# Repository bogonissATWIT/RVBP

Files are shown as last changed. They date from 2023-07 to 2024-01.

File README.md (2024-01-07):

# RVBP - Recycled Vape Battery Pack
## Sam Bogonis - Wentworth Institute of Technology 2023
#### Basic Description:
Hardware platform to harvest 13450 lithium-ion cells from disposable vape batteries and recycle them into a smart IoT WiFi-enabled USB battery pack with a web-controlled dashboard UI.
pic of final product working powered by pack
#### Platform Overview:
- 2 x USB-A Outputs
- ESP32_DEVKITC_32D Microcontroller
- 21V@1A DC Wall Charger w/ indicator LED
- 555 Power LED circuit
- DHT22 - Temperature/Humidity Sensor
- I2C 0.96" OLED Display
- Screw terminal connections for up to three packs of 5 lithium-ion cells in series
- Scalable for additional capacity
- Exposed GPIO headers for additional functionality
final-assembled-4

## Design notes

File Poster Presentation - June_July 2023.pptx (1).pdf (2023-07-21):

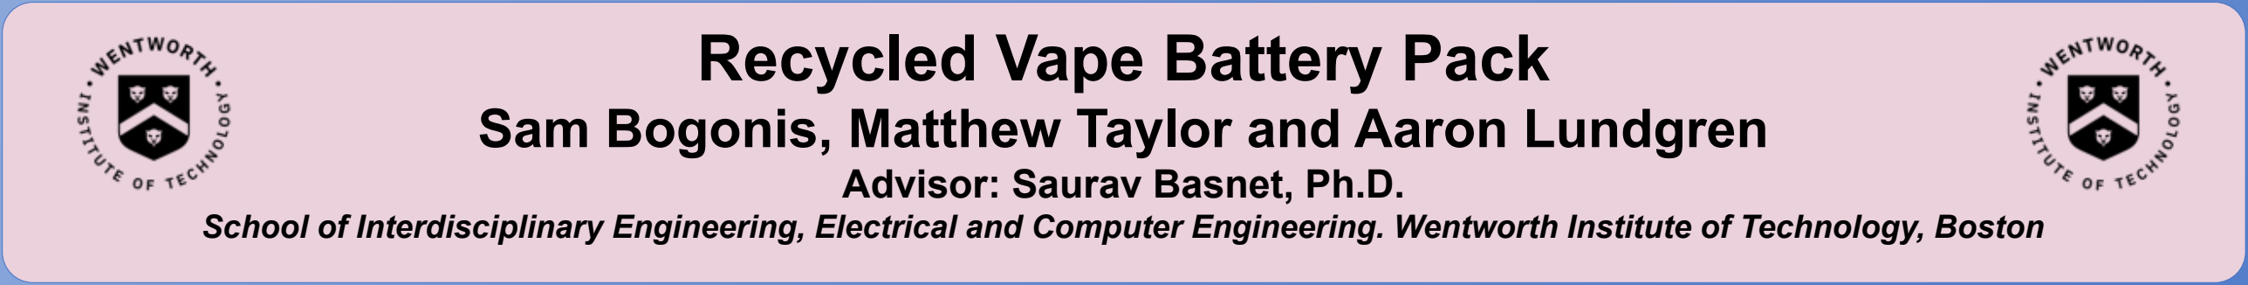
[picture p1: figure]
Recycled Vape Battery Pack; Advisor: Saurav Basnet, Ph.D.

# Sam Bogonis, Matthew Taylor and Aaron Lundgren

School of Interdisciplinary Engineering, Electrical and Computer Engineering. Wentworth Institute of Technology, Boston

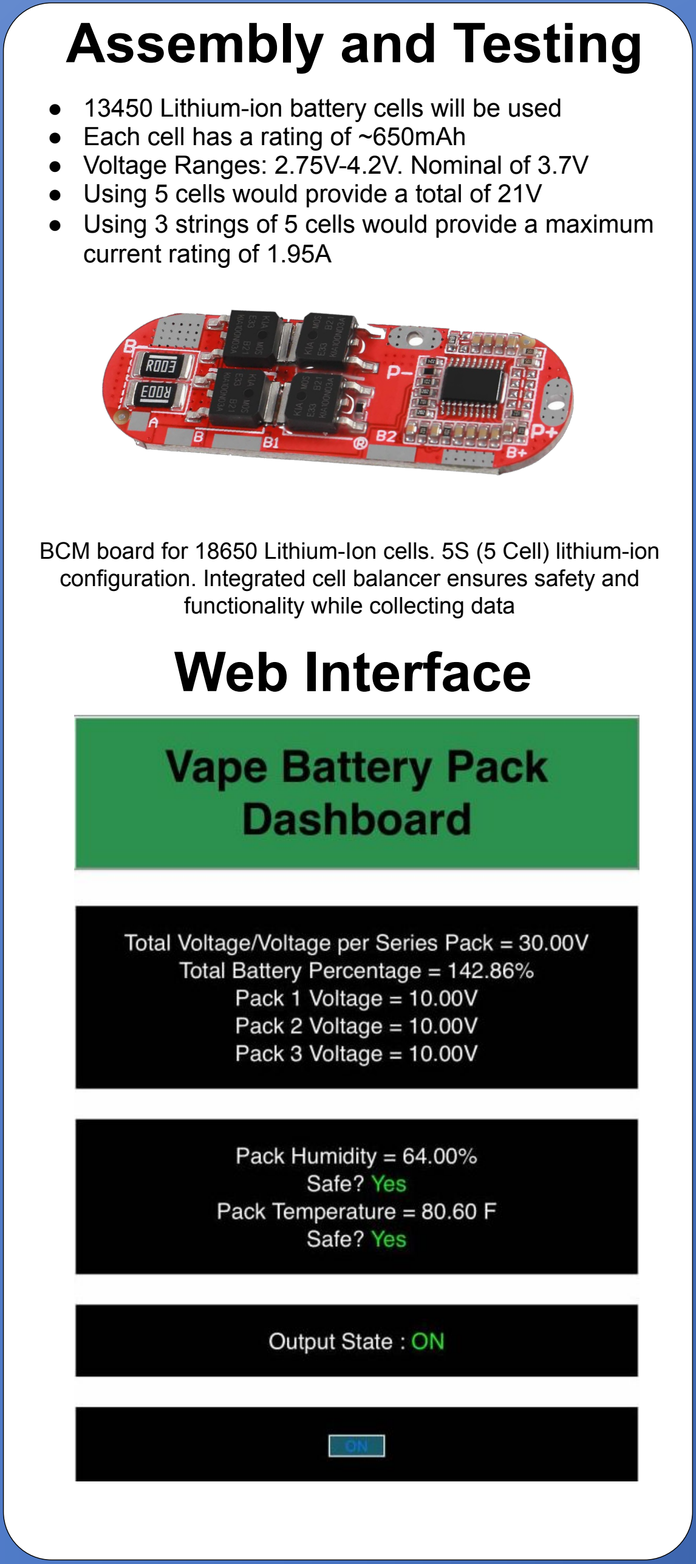
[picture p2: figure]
● Each cell has a rating of ~650mAh; current rating of 1.95A; functionality while collecting data Web Interface
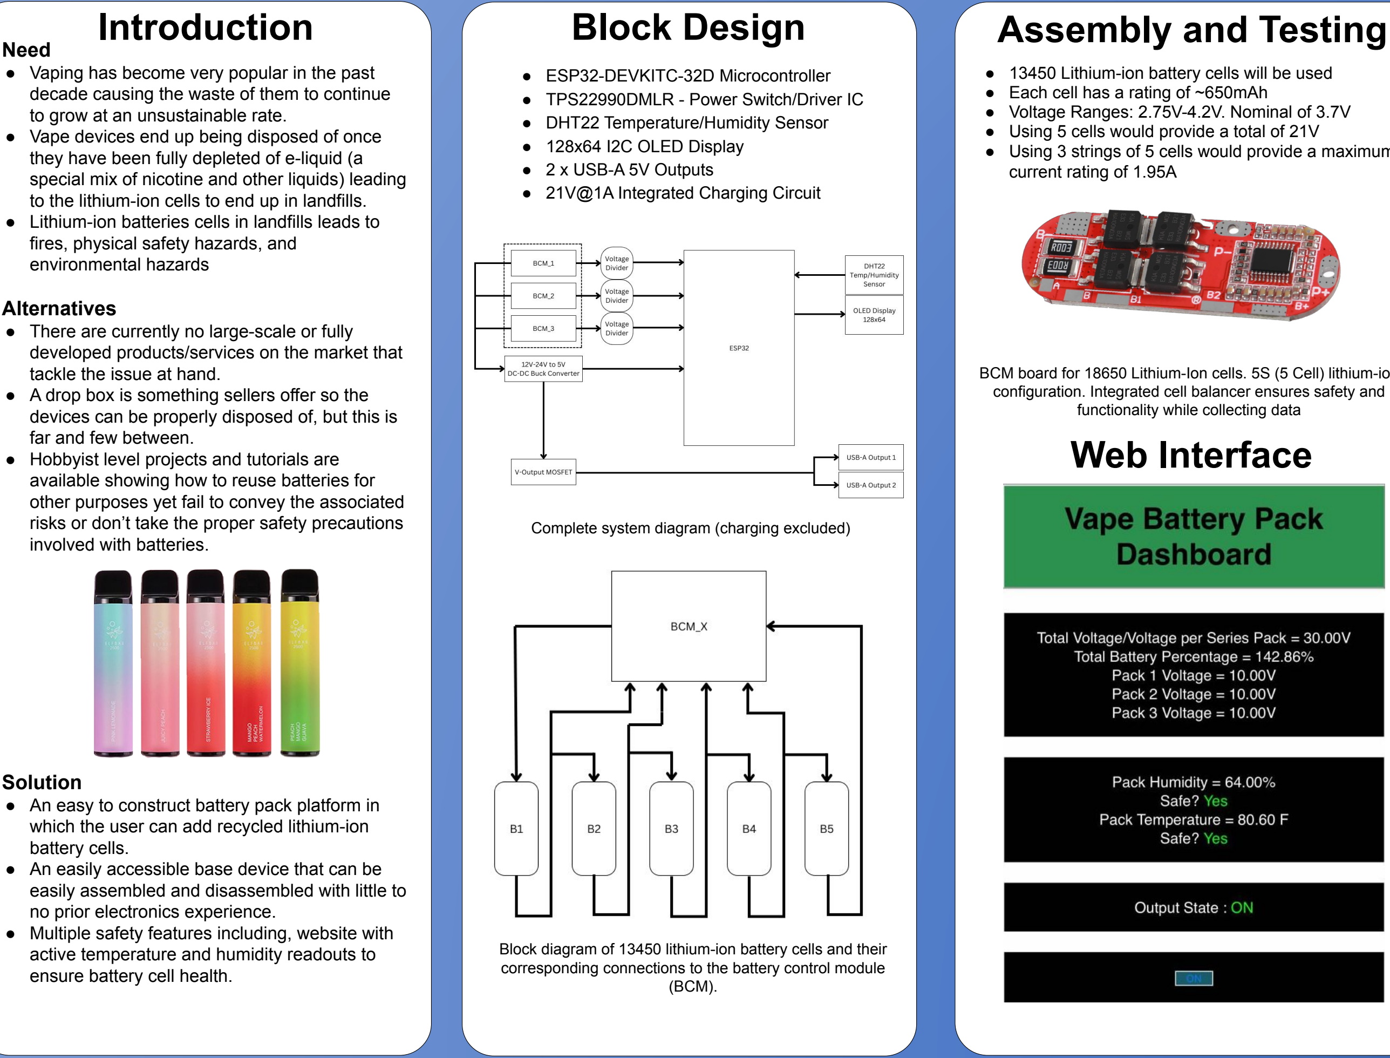
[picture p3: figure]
Block Design; ● ESP32-DEVKITC-32D Microcontroller ● TPS22990DMLR - Power Switch/Driver IC ● DHT22 Temperature/Humidity Sensor ● 128x64 I2C OLED Display ● 2 x USB-A 5V Outputs ● 21V@1A Integrated Charging Circuit; Need; to grow at an unsustainable rate.; fires, physical safety hazards, and environmental hazards; Alternatives; tackle the issue at hand.; far and few between.; involved with batteries.; Solution; battery cells.; no prior electronics experience.; ensure battery cell health.; Introduction; Assembly and Testing; Complete system diagram (charging excluded); (BCM).

- 13450 Lithium-ion battery cells will be used
- Voltage Ranges: 2.75V-4.2V. Nominal of 3.7V
- Using 5 cells would provide a total of 21V
- Using 3 strings of 5 cells would provide a maximum

# Results

[1] A. Semmens, “An innovative scheme to put 'disposable' e-cig batteries to new use,” ECigIntelligence, 15-Jul-2022. [Online]. Available: https://ecigintelligence.com/an-innovative-and-unexpected-scheme-to-put-disposable-e-cig-batteries-to-new-use/. [Accessed: 20-Mar-2023].
[2] D. Moore, “Two vapes thrown away every second,” Circular Online, 15-Jul-2022. [Online]. Available: https://www.circularonline.co.uk/news/two-vapes-thrown-away-every-second/. [Accessed: 20-Mar-2023].
[3] J. Heelan, E. Gratz, Z. Zheng, Q. Wang, M. Chen, D. Apelian, and Y. Wang, “Current and prospective Li-ion battery recycling and Recovery Processes - Jom,” SpringerLink, 20-Jun-2016. [Online]. Available: https://link.springer.com/article/10.1007/s11837-016-1994-y. [Accessed: 20-Mar-2023].
[4] Opengreenenergy and Instructables, “DIY Professional 18650 Battery Pack,” Instructables, 29-Jul-2022. [Online]. Available: https://www.instructables.com/DIY-Professional-18650-Battery-Pack/. [Accessed: 20-Mar-2023].

Conclusions
The product that this project covers is only a start to solving the issue of waste produced from disposable vapes. With the popularity continuing to grow of these devices it is important that action is taken that allows for reuse of the precious lithium inside. This product aims to be a consumer solution, giving access to a battery pack that will be easy to assemble with simple instructions.

Future Directions
An expansion of this product would take this to a manufacturer/merchant level. Drop-boxes would offer incentives as collection for the batteries. Battery cells would be harvested and used to mass produce the product or used in regular devices if battery health is optimal. Improving to that size would greatly impact the situation of vape waste.

References

- Vaping has become very popular in the past decade causing the waste of them to continue
- Vape devices end up being disposed of once they have been fully depleted of e-liquid (a special mix of nicotine and other liquids) leading to the lithium-ion cells to end up in landfills.
- Lithium-ion batteries cells in landfills leads to
- There are currently no large-scale or fully developed products/services on the market that
- A drop box is something sellers offer so the devices can be properly disposed of, but this is
- Hobbyist level projects and tutorials are available showing how to reuse batteries for other purposes yet fail to convey the associated risks or don’t take the proper safety precautions
- An easy to construct battery pack platform in which the user can add recycled lithium-ion
- An easily accessible base device that can be easily assembled and disassembled with little to
- Multiple safety features including, website with active temperature and humidity readouts to

Block diagram of 13450 lithium-ion battery cells and their corresponding connections to the battery control module

BCM board for 18650 Lithium-Ion cells. 5S (5 Cell) lithium-ion configuration. Integrated cell balancer ensures safety and

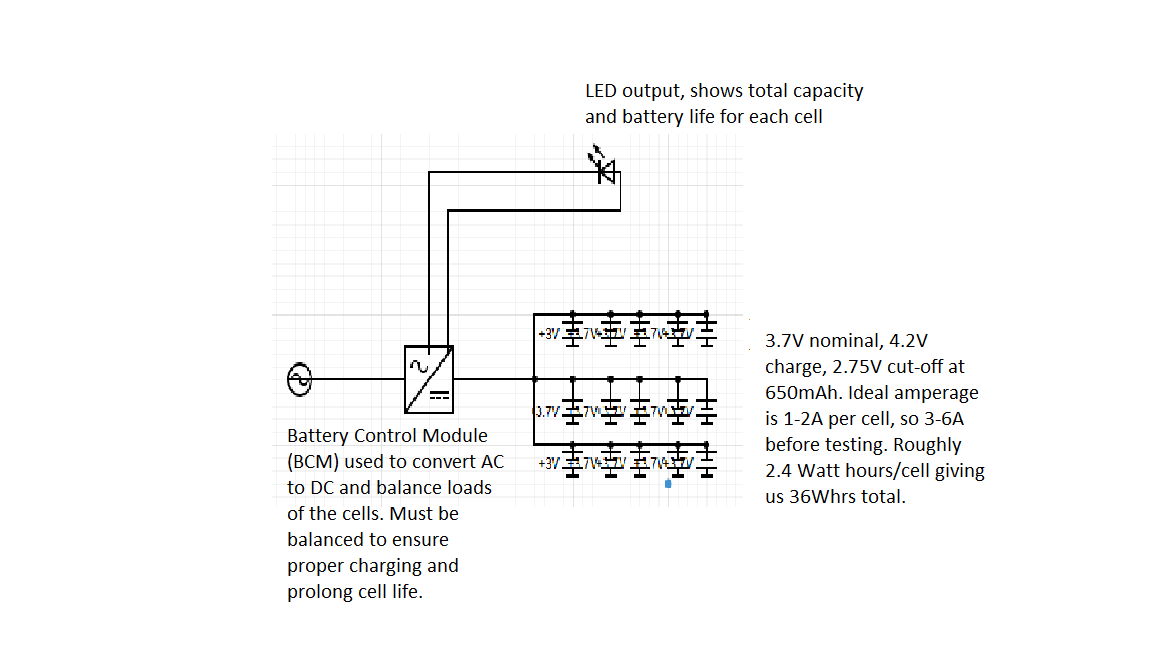
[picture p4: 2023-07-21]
System Block Diagram/circuit prototype.png

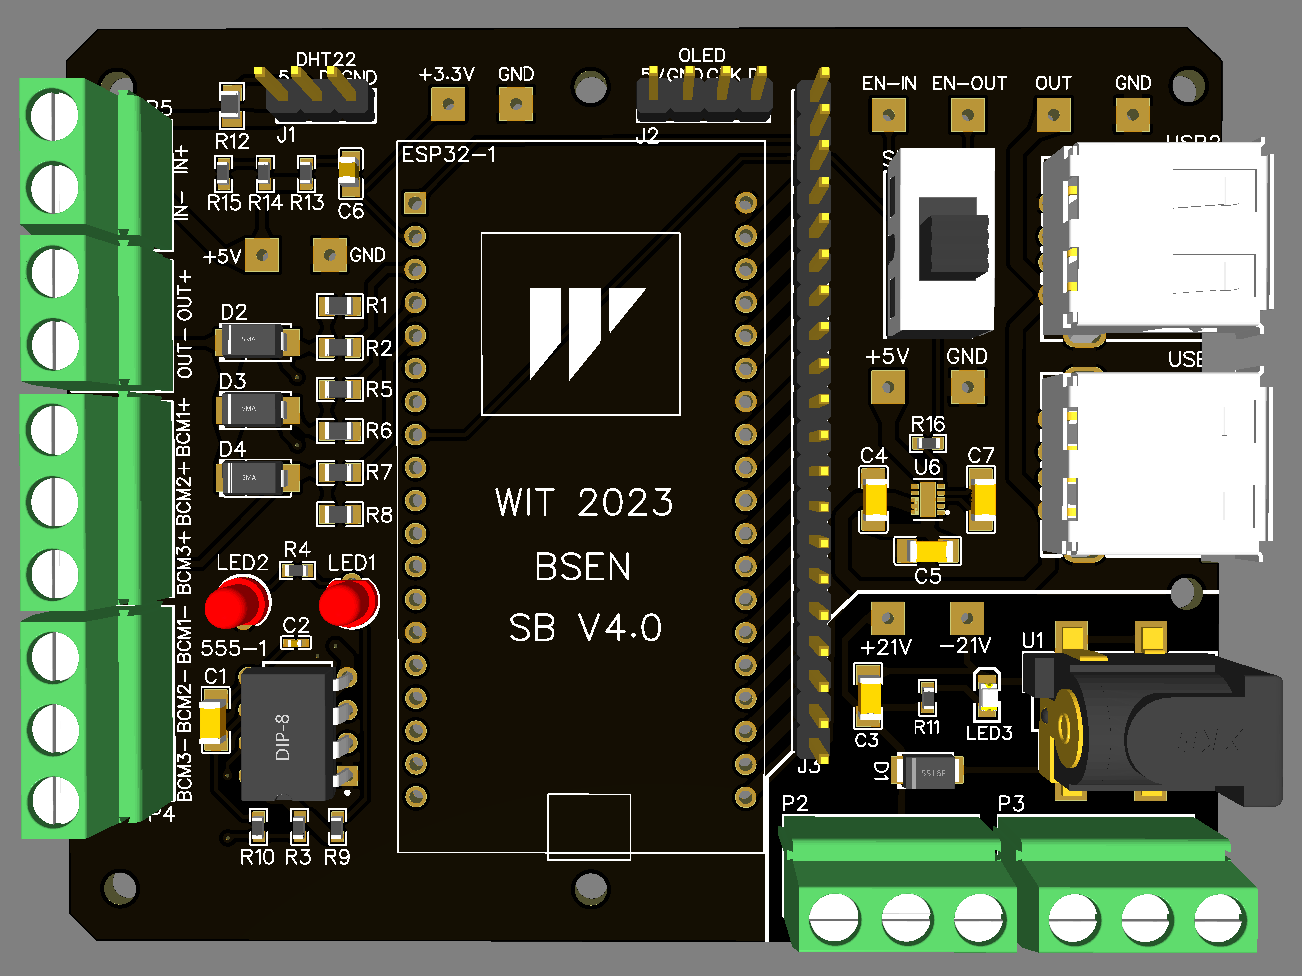
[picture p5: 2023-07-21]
V4.0/V4-Model1.png

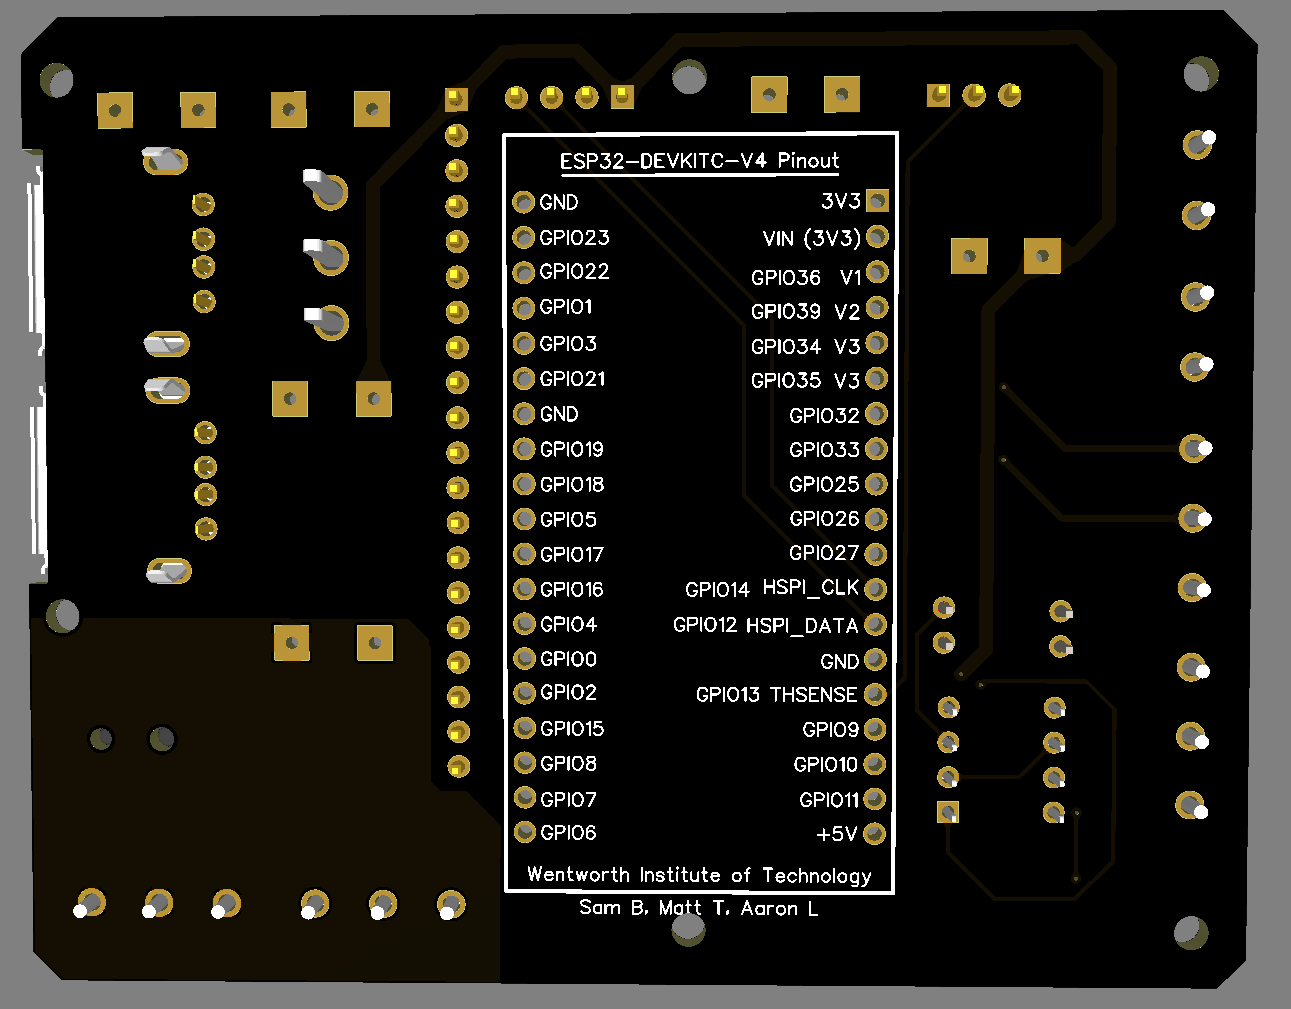
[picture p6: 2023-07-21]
V4.0/V4-Model2.png

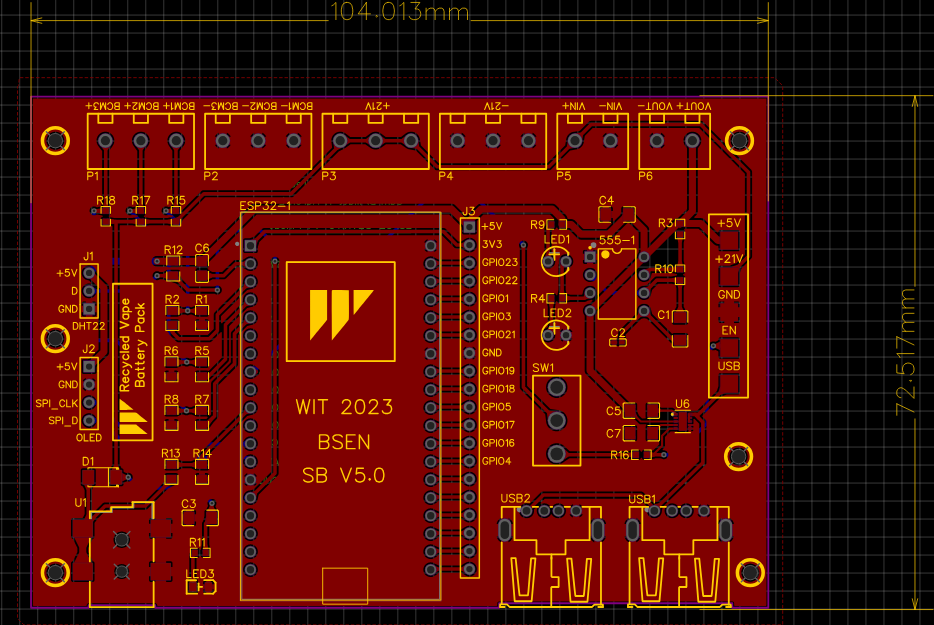
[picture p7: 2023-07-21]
V5.0 - Final/PCB-1.png

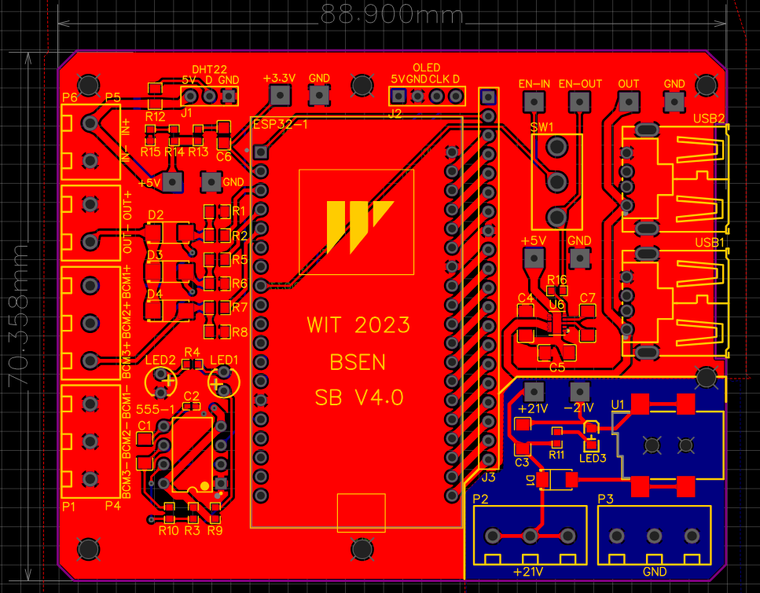
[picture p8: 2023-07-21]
V4.0/V4-Final.png

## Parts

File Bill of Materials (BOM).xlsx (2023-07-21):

QTY | Name | Price | Price (Calculated) | Complete | URL
1 | 21V/1A Wall Charger | $8.17 | $8.17 |  | https://www.amazon.com/dp/B09THJCD8Q/?coliid=I156PEE71VQ26Z&colid=3LVNL31IXG1PE | Delivered
1 | DHT22 Temp/Humidity Sensor | $13.99 | $13.99 |  | https://www.amazon.com/dp/B0795F19W6/?coliid=IOJO4XWYG3GXL&colid=3LVNL31IXG1PE | Waiting
1 | 128x63 0.96inch OLED Display | $10.99 | $10.99 |  | https://www.amazon.com/dp/B0BK4QVR1F/?coliid=I14K05QKVUBQC6&colid=3LVNL31IXG1PE | On the way
1 | Adhesive Foam Pad 1/4"x4"x4" | $10.88 | $10.88 |  | https://www.amazon.com/dp/B06ZY83SZJ/?coliid=IFWQ253B9FA2G&colid=3LVNL31IXG1PE | Not yet acquired
2 | 2pcs 21V 5S BMS PCB | $9.99 | $19.98 |  | https://www.amazon.com/dp/B08R9G6S7Y/?coliid=I1HXKP7RCFCFKY&colid=3LVNL31IXG1PE
2 | 25W DC-DC 12V/24V-5V Buck Reg. | $12.99 | $25.98 |  | https://www.amazon.com/dp/B09SD9SH8C/?coliid=I266TNYB8VDANJ&colid=3LVNL31IXG1PE
1 | 2" Nickel Strips, 50pcs | $5.49 | $5.49 |  | https://www.amazon.com/dp/B07PQP55CM?psc=1&ref=ppx_yo2ov_dt_b_product_details
10 | TPS22990DMLR | $0.93 | $9.30 |  | https://www.digikey.com/en/products/detail/texas-instruments/TPS22990DMLR/6148959
6 | ESP32-DEVKITC-32D Microcontroller | $10.00 | $60.00 |  | https://www.digikey.com/en/products/detail/espressif-systems/ESP32-DEVKITC-32D/9356990
1 | Prototype PCB (5)Manufacture/(2)Assembly | $57.29 | $57.29
1 | Final PCB (10)Manufacture/(6)Assembly | $94.13 | $94.13
3 | 3pcs 21V Balancer PCB | $7.99 | $23.97 |  | https://www.amazon.com/dp/B09F9K7X34?psc=1&ref=ppx_yo2ov_dt_b_product_details
1 | 20pairs Nickel Plate Spring Contacts | $8.99 | $8.99 |  | https://www.amazon.com/dp/B07HRTMY5T?psc=1&ref=ppx_yo2ov_dt_b_product_details
 |  | Total: | $349.16
 |  | Remaining: | $193.42
 |  | Split Cost (3): | $64.47

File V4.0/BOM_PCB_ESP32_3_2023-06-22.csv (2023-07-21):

ID | Name | Designator | Footprint | Quantity | Manufacturer Part | Manufacturer | Supplier | Supplier Part | Price
1 | DC-005-2.5A-2.5-SMT | U1 | DC-IN-TH_XKB_DC-005-2.5A-2.5-SMT | 1 | DC-005-2.5A-2.5-SMT | XKB Connectivity(中国星坤) | LCSC | C2880544 | 0.324
2 | WJ126V-5.0-2P | P5,P6 | CONN-TH_WJ126V-5.0-2P | 2 | WJ126V-5.0-2P | KANGNEX(康奈克斯电气) | LCSC | C8404 | 0.068
3 | FC-2012HRK-620D | LED3 | LED0805-RD_RED | 1 | NCD0805R1 | 国星光电 | LCSC | C84256 | 0.011
4 | 1kΩ | R11,R3,R4,R9 | R0603 | 4 | 0603WAF1001T5E | UNI-ROYAL(厚声) | LCSC | C21190 | 0.001
5 | NE555P | 555-1 | DIP-8_L9.8-W6.6-P2.54-LS7.6-BL | 1 | NE555P | TI(德州仪器) | LCSC | C46749 | 0.262
6 | 10uF | C1,C5,C7 | C1206 | 3 | CS3216X7R106K250NRI | SAMWHA(三和) | LCSC | C513767 | 0.039
7 | 22uF | C3,C4 | C1206 | 2 | CS3216X5R226K160NRI | SAMWHA(三和) | LCSC | C513771 | 0.064
8 | 10nF | C2 | C0402 | 1 | GRM155B11E103KA01D | muRata(村田) | LCSC | C85947 | 0.002
9 | 200nF | C6 | C0805 | 1 | NL0805B204K500CPBN | HUI JU(汇聚) | LCSC | C918135 | 0.012
10 | PMEG3020EP,115 | D1 | SMAF_L3.8-W2.5-LS4.7-RD | 1 | PMEG3020EP,115 | Nexperia(安世) | LCSC | C513108 | 0.218
11 | SS34_C8678 | D2,D3,D4 | SMA_L4.3-W2.6-LS5.2-RD | 3 | SS34 | MDD | LCSC | C8678 | 0.024
12 | ESP32-DEVKITC-32D_ESP32-DEVKITC-32D | ESP32-1 | ESP32-DEVKITC-32D_MODULE_ESP32-DEVKITC-32D | 1
13 | HDR-M-2.54_1x3 | J1 | HDR-M-2.54_1X3 | 1 |  |  | LCSC | C180248 | 0.197
14 | HDR-M-2.54_1x4 | J2 | HDR-M-2.54_1X4 | 1 |  |  | LCSC | C124378 | 0.042
15 | HDR-M-2.54_1x20 | J3 | HDR-M-2.54_1X20 | 1 |  |  | LCSC | C50981 | 0.091
16 | *1 | LED1,LED2 | LED-TH_BD3.8-P2.54-FD | 2 | 204-10SYGD/S530-E3 | EVERLIGHT(亿光) | LCSC | C85161 | 0.029
17 | WJ126V-5.0-3P | P1,P2,P3,P4 | CONN-TH_3P-P5.00_WJ126V-5.0-3P | 4 | WJ126V-5.0-3P | KANGNEX(康奈克斯电气) | LCSC | C8401 | 0.101
18 | 3kΩ | R1,R6,R8 | R0805 | 3 | 0805W8F3001T5E | UNI-ROYAL(厚声) | LCSC | C17661 | 0.002
19 | 20kΩ | R2,R5,R7 | R0805 | 3 | 0805W8F2002T5E | UNI-ROYAL(厚声) | LCSC | C4328 | 0.002
20 | 10kΩ | R12 | R0805 | 1 | 0805W8F1002T5E | UNI-ROYAL(厚声) | LCSC | C17414 | 0.001
21 | 100kΩ | R10,R13,R14,R15 | R0603 | 4 | 0603WAF1003T5E | UNI-ROYAL(厚声) | LCSC | C25803 | 0.001
22 | 0Ω | R16 | R0603 | 1 | 0603WAF0000T5E | UNI-ROYAL(厚声) | LCSC | C21189 | 0.001
23 | SS-12D10L5 | SW1 | SW-TH_SS-12D10L5 | 1 | SS-12D10L5 | XKB Connectivity(中国星坤) | LCSC | C319012 | 0.283
24 | TPS22990DMLR | U6 | WSON-10_L3.0-W2.0-P0.50-BL-EP_TI_DML | 1 | TPS22990DMLR | TI(德州仪器) | LCSC | C962990 | 0.741
25 | U-USBAR04P-F001 | USB1,USB2 | USB-A-TH_USB-302-T | 2 | U-USBAR04P-F002 | Ckmtw(灿科盟) | LCSC | C386736 | 0.174

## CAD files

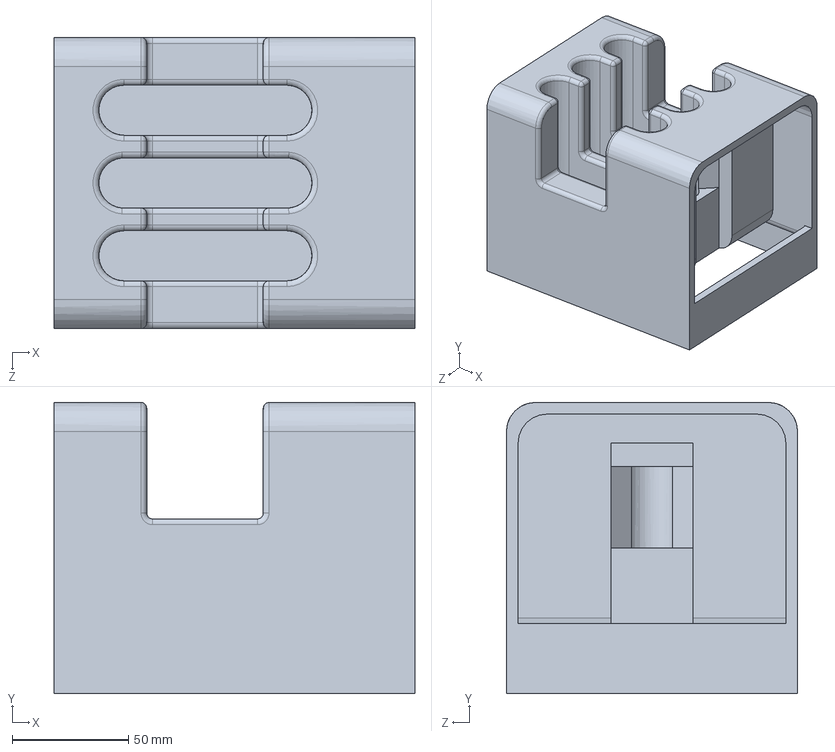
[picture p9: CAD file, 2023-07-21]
Solidworks/Enclosure.SLDPRT
155.0 x 125.0 x 125.0 mm

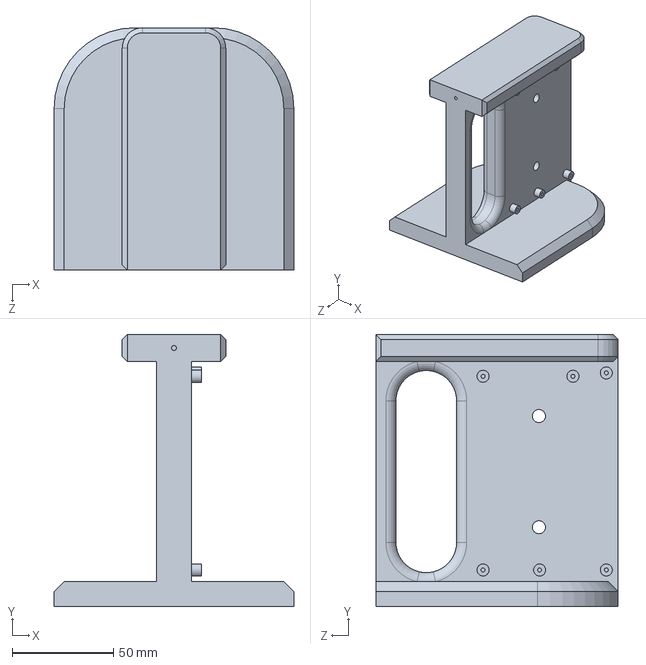
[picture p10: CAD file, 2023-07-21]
Solidworks/presentation base.SLDPRT
118.7 x 134.6 x 120.0 mm

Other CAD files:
Solidworks/Enclosure.STL
Solidworks/presentation base.STL

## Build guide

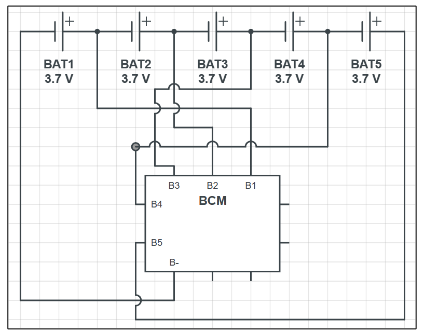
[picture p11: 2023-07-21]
System Block Diagram/Cell setup.png

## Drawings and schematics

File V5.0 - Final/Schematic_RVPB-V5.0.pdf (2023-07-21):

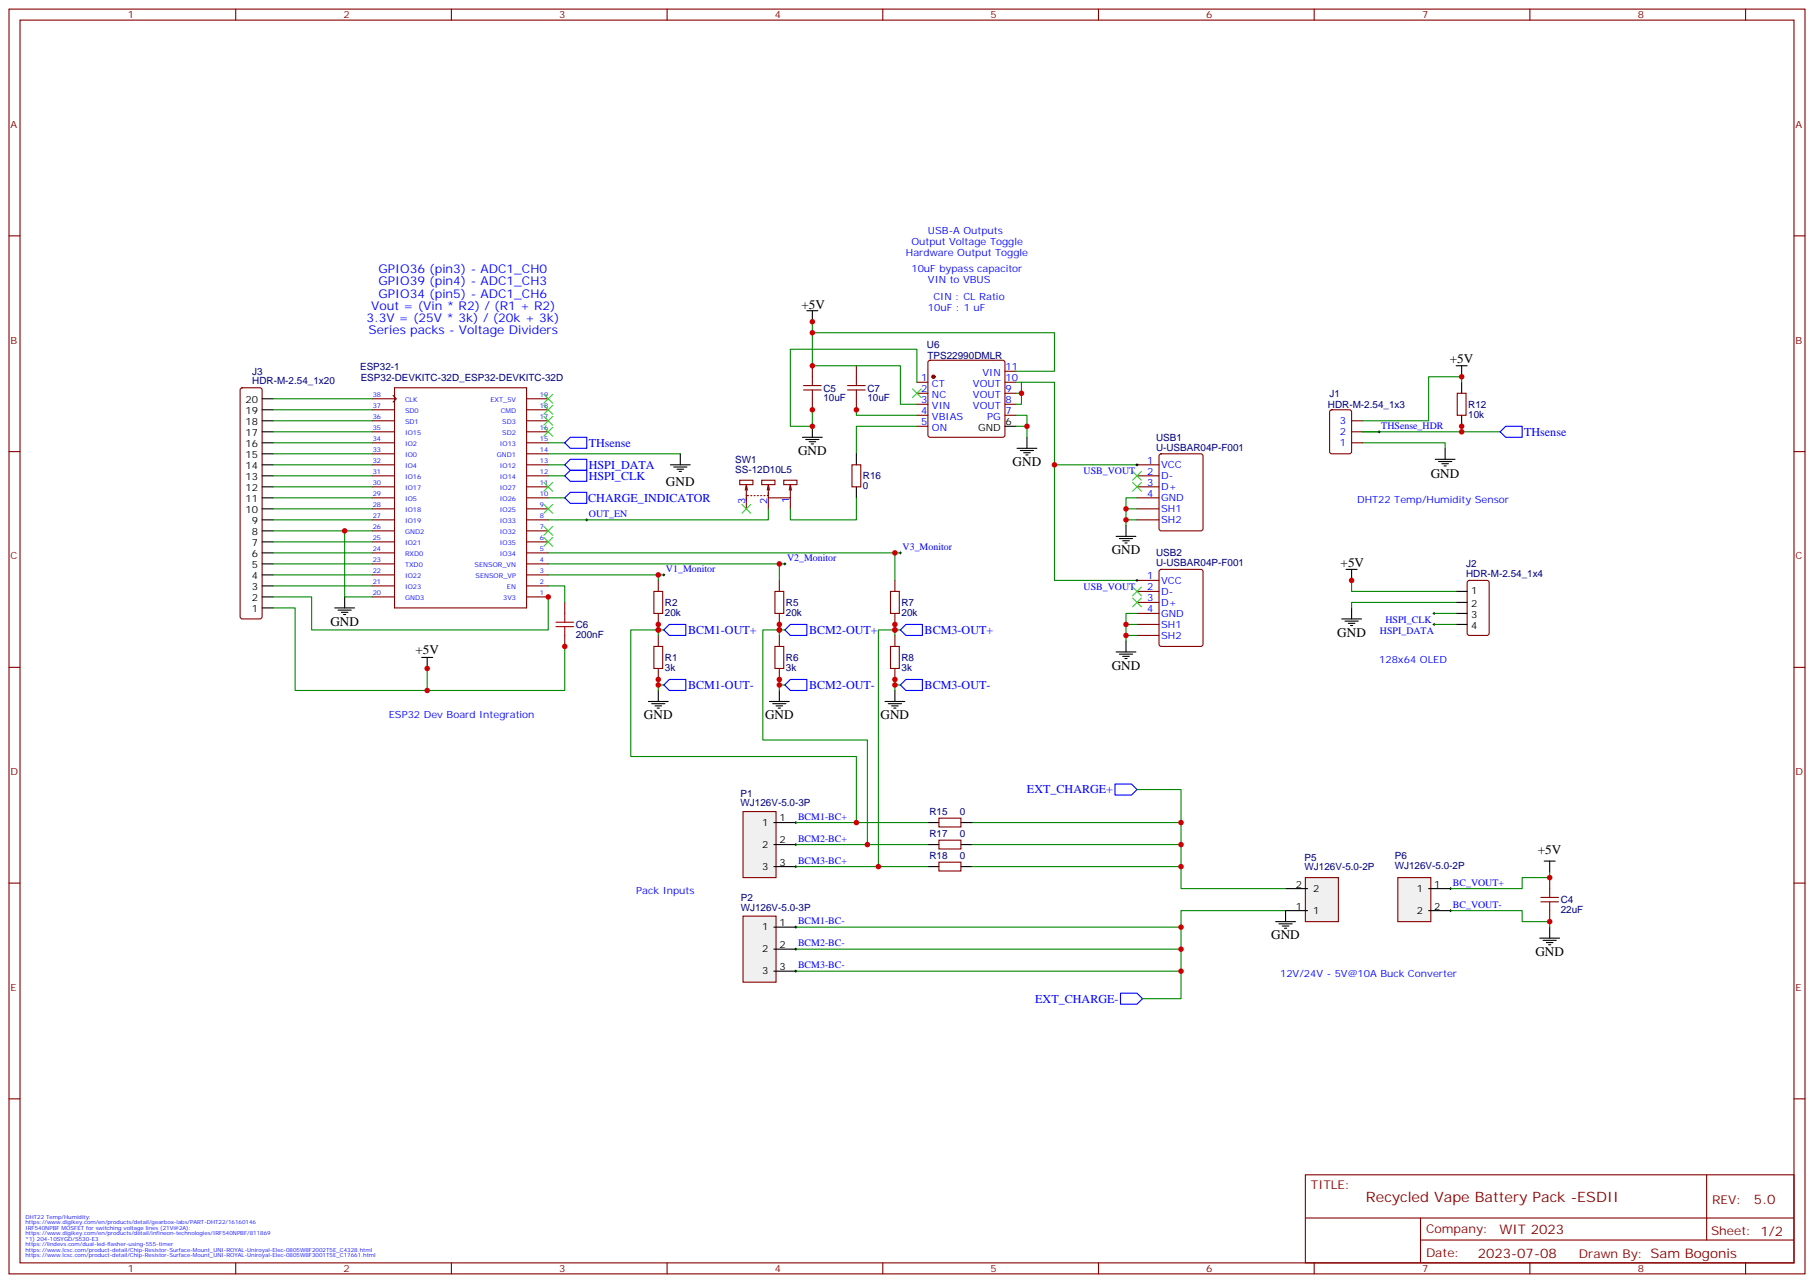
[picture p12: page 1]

DHT22 Temp/Humidity:
https://www.digikey.com/en/products/detail/gearbox-labs/PART-DHT22/16160146
IRF540NPBF MOSFET for switching voltage lines (21V@2A):
https://www.digikey.com/en/products/detail/infineon-technologies/IRF540NPBF/811869
*1) 204-10SYGD/S530-E3
https://lindevs.com/dual-led-flasher-using-555-timer
https://www.lcsc.com/product-detail/Chip-Resistor-Surface-Mount_UNI-ROYAL-Uniroyal-Elec-0805W8F2002T5E_C4328.html
https://www.lcsc.com/product-detail/Chip-Resistor-Surface-Mount_UNI-ROYAL-Uniroyal-Elec-0805W8F3001T5E_C17661.html

Drawn By: Sam Bogonis

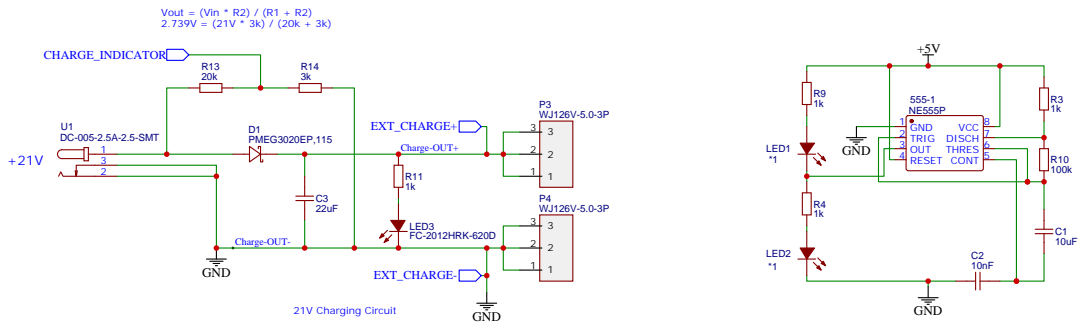
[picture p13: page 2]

Drawn By: Sam Bogonis

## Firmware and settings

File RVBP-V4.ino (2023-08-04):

#include <AsyncTCP.h>

#include "ESPAsyncWebServer.h"

#include <WiFi.h>
#include <DHT.h>
#include <Wire.h>
#include <Adafruit_GFX.h>
#include <Adafruit_SSD1306.h>
#include <U8g2lib.h>
#include <Fonts/FreeMonoBold9pt7b.h>
#include <Fonts/Picopixel.h>
#include <Fonts/FreeSerif9pt7b.h>
#include <Fonts/TomThumb.h>
#include <Fonts/Org_01.h>
#define VPack_1 36
#define VPack_2 39
#define VPack_3 34
#define THSense 13
#define OUT_Toggle 33
#define SCREEN_WIDTH 128 // OLED display width, in pixels
#define SCREEN_HEIGHT 64 // OLED display height, in pixels


//WIT Logo bitmap
const unsigned char wit_logo [] PROGMEM = {
	0xff, 0xff, 0xff, 0xff, 0xff, 0xff, 0xff, 0xff, 0xff, 0xff, 0xff, 0xff, 0xff, 0xff, 0xff, 0xff, 
	0xff, 0xff, 0xff, 0xff, 0xff, 0xff, 0xff, 0xff, 0xff, 0xff, 0xff, 0xff, 0xff, 0xff, 0xff, 0xff, 
	0xff, 0xff, 0xff, 0xff, 0xff, 0xff, 0xff, 0xff, 0xff, 0xff, 0xff, 0xff, 0xff, 0xff, 0xff, 0xff, 
	0xff, 0xff, 0xff, 0xff, 0xff, 0xff, 0xff, 0xff, 0xff, 0xff, 0xff, 0xff, 0xff, 0xff, 0xff, 0xff, 
	0xff, 0xff, 0xff, 0xff, 0xff, 0xff, 0xff, 0xff, 0xff, 0xff, 0xff, 0xff, 0xff, 0xff, 0xff, 0xff, 
	0xff, 0xff, 0xff, 0xff, 0xff, 0xff, 0xff, 0xff, 0xff, 0xff, 0xff, 0xff, 0xff, 0xff, 0xff, 0xff, 
	0xff, 0xff, 0xff, 0xff, 0xff, 0xff, 0xff, 0xff, 0xff, 0xff, 0xff, 0xff, 0xff, 0xff, 0xff, 0xff, 
	0xff, 0xff, 0xff, 0xff, 0xff, 0xff, 0xff, 0xff, 0xff, 0xff, 0xff, 0xff, 0xff, 0xff, 0xff, 0xff, 
	0xff, 0xff, 0xff, 0xff, 0xff, 0xff, 0xff, 0xff, 0xff, 0xff, 0xff, 0xff, 0xff, 0xff, 0xff, 0xff, 
	0xff, 0xff, 0xff, 0xff, 0xff, 0xff, 0xff, 0xff, 0xff, 0xff, 0xff, 0xff, 0xff, 0xff, 0xff, 0xff, 
	0xff, 0xff, 0xff, 0xff, 0xf8, 0x00, 0x1e, 0x00, 0x03, 0xc0, 0x00, 0x1f, 0xff, 0xff, 0xff, 0xff, 
	0xff, 0xff, 0xff, 0xff, 0xf8, 0x00, 0x1e, 0x00, 0x03, 0xc0, 0x00, 0x3f, 0xff, 0xff, 0xff, 0xff, 
	0xff, 0xff, 0xff, 0xff, 0xf8, 0x00, 0x1e, 0x00, 0x03, 0xc0, 0x00, 0x7f, 0xff, 0xff, 0xff, 0xff, 
	0xff, 0xff, 0xff, 0xff, 0xf8, 0x00, 0x1e, 0x00, 0x03, 0xc0, 0x00, 0xff, 0xff, 0xff, 0xff, 0xff, 
	0xff, 0xff, 0xff, 0xff, 0xf8, 0x00, 0x1e, 0x00, 0x03, 0xc0, 0x00, 0xff, 0xff, 0xff, 0xff, 0xff, 
	0xff, 0xff, 0xff, 0xff, 0xf8, 0x00, 0x1e, 0x00, 0x03, 0xc0, 0x01, 0xff, 0xff, 0xff, 0xff, 0xff, 
	0xff, 0xff, 0xff, 0xff, 0xf8, 0x00, 0x1e, 0x00, 0x03, 0xc0, 0x03, 0xff, 0xff, 0xff, 0xff, 0xff, 
	0xff, 0xff, 0xff, 0xff, 0xf8, 0x00, 0x1e, 0x00, 0x03, 0xc0, 0x07, 0xff, 0xff, 0xff, 0xff, 0xff, 
	0xff, 0xff, 0xff, 0xff, 0xf8, 0x00, 0x1e, 0x00, 0x03, 0xc0, 0x0f, 0xff, 0xff, 0xff, 0xff, 0xff, 
	0xff, 0xff, 0xff, 0xff, 0xf8, 0x00, 0x1e, 0x00, 0x03, 0xc0, 0x0f, 0xff, 0xff, 0xff, 0xff, 0xff, 
	0xff, 0xff, 0xff, 0xff, 0xf8, 0x00, 0x1e, 0x00, 0x03, 0xc0, 0x1f, 0xff, 0xff, 0xff, 0xff, 0xff, 
	0xff, 0xff, 0xff, 0xff, 0xf8, 0x00, 0x1e, 0x00, 0x03, 0xc0, 0x3f, 0xff, 0xff, 0xff, 0xff, 0xff, 
	0xff, 0xff, 0xff, 0xff, 0xf8, 0x00, 0x1e, 0x00, 0x03, 0xc0, 0x7f, 0xff, 0xff, 0xff, 0xff, 0xff, 
	0xff, 0xff, 0xff, 0xff, 0xf8, 0x00, 0x1e, 0x00, 0x03, 0xc0, 0xff, 0xff, 0xff, 0xff, 0xff, 0xff, 
	0xff, 0xff, 0xff, 0xff, 0xf8, 0x00, 0x1e, 0x00, 0x03, 0xc0, 0xff, 0xff, 0xff, 0xff, 0xff, 0xff, 
	0xff, 0xff, 0xff, 0xff, 0xf8, 0x00, 0x1e, 0x00, 0x03, 0xc1, 0xff, 0xff, 0xff, 0xff, 0xff, 0xff, 
	0xff, 0xff, 0xff, 0xff, 0xf8, 0x00, 0x1e, 0x00, 0x03, 0xc3, 0xff, 0xff, 0xff, 0xff, 0xff, 0xff, 
	0xff, 0xff, 0xff, 0xff, 0xf8, 0x00, 0x1e, 0x00, 0x03, 0xc7, 0xff, 0xff, 0xff, 0xff, 0xff, 0xff, 
	0xff, 0xff, 0xff, 0xff, 0xf8, 0x00, 0x1e, 0x00, 0x03, 0xc7, 0xff, 0xff, 0xff, 0xff, 0xff, 0xff, 
	0xff, 0xff, 0xff, 0xff, 0xf8, 0x00, 0x1e, 0x00, 0x03, 0xcf, 0xff, 0xff, 0xff, 0xff, 0xff, 0xff, 
	0xff, 0xff, 0xff, 0xff, 0xf8, 0x00, 0x1e, 0x00, 0x03, 0xdf, 0xff, 0xff, 0xff, 0xff, 0xff, 0xff, 
	0xff, 0xff, 0xff, 0xff, 0xf8, 0x00, 0x1e, 0x00, 0x03, 0xff, 0xff, 0xff, 0xff, 0xff, 0xff, 0xff, 
	0xff, 0xff, 0xff, 0xff, 0xf8, 0x00, 0x1e, 0x00, 0x03, 0xff, 0xff, 0xff, 0xff, 0xff, 0xff, 0xff, 
	0xff, 0xff, 0xff, 0xff, 0xf8, 0x00, 0x1e, 0x00, 0x03, 0xff, 0xff, 0xff, 0xff, 0xff, 0xff, 0xff, 
	0xff, 0xff, 0xff, 0xff, 0xf8, 0x00, 0x1e, 0x00, 0x03, 0xff, 0xff, 0xff, 0xff, 0xff, 0xff, 0xff, 
	0xff, 0xff, 0xff, 0xff, 0xf8, 0x00, 0x1e, 0x00, 0x03, 0xff, 0xff, 0xff, 0xff, 0xff, 0xff, 0xff, 
	0xff, 0xff, 0xff, 0xff, 0xf8, 0x00, 0x3e, 0x00, 0x07, 0xff, 0xff, 0xff, 0xff, 0xff, 0xff, 0xff, 
	0xff, 0xff, 0xff, 0xff, 0xf8, 0x00, 0x3e, 0x00, 0x0f, 0xff, 0xff, 0xff, 0xff, 0xff, 0xff, 0xff, 
	0xff, 0xff, 0xff, 0xff, 0xf8, 0x00, 0x7e, 0x00, 0x0f, 0xff, 0xff, 0xff, 0xff, 0xff, 0xff, 0xff, 
	0xff, 0xff, 0xff, 0xff, 0xf8, 0x00, 0xfe, 0x00, 0x1f, 0xff, 0xff, 0xff, 0xff, 0xff, 0xff, 0xff, 
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
};

const char index_html[] PROGMEM = R"rawliteral(
<!DOCTYPE HTML><html>
<!-- CSS Contents -->
<head>
  <meta name="viewport" content="width=device-width, initial-scale=1.0">
  <link rel="stylesheet" href="https://use.fontawesome.com/releases/v5.7.2/css/all.css" integrity="sha384-fnmOCqbTlWIlj8LyTjo7mOUStjsKC4pOpQbqyi7RrhN7udi9RwhKkMHpvLbHG9Sr" crossorigin="anonymous">
  <style>
    html {
     font-family: Arial;
     display: inline-block;
     margin: 0px auto;
     text-align: center;
    }
    h2 { 
      font-size: 3.0rem; 
      background-color: #4287f5;
      color: white;
      text-shadow: #474747 3px 5px 2px;
    }
    body {
      background-color: #232933;
      color: white;
    }
    @media screen and (prefers-color-scheme: light) {
      body {
        background-color: white;
        color: black;
      }
    }
    p { 
      font-size: 3.0rem; 
    }
    pBody {
      font-size: 1.2rem;
      color: black;
    }
    .units { 
      font-size: 1.2rem; 
    }
    .dht-labels {
      font-size: 1.5rem;
      vertical-align:middle;
      padding-bottom: 5px;
    }
    .collapsible {
      background-color: #4287f5;
      color: white;
      cursor: pointer;
      padding: 18px;
      min-width: 100%; <!-- this might cause issues on mobile -->
      border: none;
      text-align: left;
      outline: none;
      font-size: 15px;
    }
    .active, .collapsible:hover {
      background-color: #555;
    }
    .collapsible:after {
      content: '\002B';
      color: white;
      font-weight: bold;
      float: right;
      margin-left: 5px;
    }
    .active:after {
      content: "\2212";
    }
    .content {
      padding: 0 18px;
      max-height: 0;
      overflow: hidden;
      transition: max-height 0.5s ease-out;
      background-color: #f1f1f1;
    }
  </style>

</head>
<!-- HTML Contents -->
<body>
  <h2>RVBP<br>Dashboard</h2>
  <p>
    <i class="fas fa-thermometer-half" style="color:#059e8a;"></i> 
    <span class="dht-labels">Temperature:</span> 
    <span id="temperature">%TEMPERATURE%</span>
    <sup class="units">&deg;F</sup>
  </p>
  <p>
    <i class="fas fa-tint" style="color:#00add6;"></i> 
    <span class="dht-labels">Humidity:</span>
    <span id="humidity">%HUMIDITY%</span>
    <sup class="units">&percnt;</sup>
  </p>
  <p>
    <span class="dht-labels">Pack 1:</span>
    <span id="v1voltage">%V1VOLTAGE%</span>
    <sup class="units">V</sup>
  </p>
  <p>
    <span class="dht-labels">Pack 2:</span>
    <span id="v2voltage">%V2VOLTAGE%</span>
    <sup class="units">V</sup>
  </p>
  <p>
    <span class="dht-labels">Pack 3:</span>
    <span id="v3voltage">%V3VOLTAGE%</span>
    <sup class="units">V</sup>
  </p>
  <p>
    <span class="dht-labels">Total Voltage:</span>
    <span id="totalvoltage">%TOTALVOLTAGE%</span>
    <sup class="units">V</sup>
  </p>
  <p>
    <span class="dht-labels">Charge Percentage:</span>
    <span id="chargepercent">%CHARGEPERCENT%</span>
    <sup class="units">&percnt;</sup>
  </p>
  <span>
  <button class="collapsible">About</button>
  <div class="content">
    <pBody>
    The RVBP (Recycled Vape Battery Pack) project focuses on recycling lithium-ion batteries from disposable vaping devices to create a smart IoT USB battery pack.
     By refurbishing these batteries, we aim to reduce electronic waste and promote sustainability. The battery pack combines 15 recycled lithium-ion batteries,
      connecting 5 cells in series and arranging 3 packs of 5 cells in parallel (5S3P configuration), delivering enhanced capacity and voltage stability.
       Users can monitor real-time battery performance, including voltages, charge capacity, temperature, and humidity, through an intuitive web dashboard.
        RVBP strives to provide an eco-friendly and efficient power solution, contributing to a cleaner and greener environment.
    </pBody>
  </div>
  </span>
  <br>
  <span>
  <button class="collapsible">Quick Facts</button>
  <div class="content">
    <pBody>
    <b>Widespread Usage:</b> Lithium-ion batteries are the most commonly used rechargeable batteries in various applications, including smartphones, laptops, electric vehicles, and portable electronics. Their lightweight and high energy density make them a preferred choice for modern technology.<br>
    <b>Resource Intensive:</b> The production of lithium-ion batteries involves mining and processing scarce and valuable resources such as lithium, cobalt, and nickel. These mining activities can lead to environmental degradation and ecological disruption in the regions where these resources are extracted.<br>
    <b>Electronic Waste:</b> As the demand for lithium-ion batteries grows, so does the problem of electronic waste. Improper disposal or recycling of used batteries can lead to hazardous chemicals, including lithium and cobalt, leaching into the soil and water, causing environmental contamination.<br>
    <b>Energy-Intensive Recycling:</b> While recycling lithium-ion batteries is crucial for sustainability, the recycling process itself requires significant energy input. Energy-intensive methods used to recycle these batteries can potentially offset some of the environmental benefits.<br>
    <b>Transportation Challenges:</b> The transportation of lithium-ion batteries from manufacturers to end-users can contribute to carbon emissions, especially when dealing with large-scale electric vehicle batteries or bulk shipments.<br>
    <b>Fire Risk:</b> In rare cases, lithium-ion batteries can experience thermal runaway, leading to fires or explosions. Improper handling and disposal of damaged or defective batteries can exacerbate the risks of accidents.<br>
    <b>Sustainable Solutions:</b> To mitigate the environmental impact of lithium-ion batteries, efforts are being made to develop sustainable battery chemistries, recycling methods, and environmentally friendly materials sourcing.
        Research is ongoing to find alternatives to critical resources like cobalt, which will reduce the environmental burden of battery production.<br>
    <b>Extended Lifespan:</b> Extending the lifespan of lithium-ion batteries through proper care and maintenance can reduce the frequency of disposal and the associated environmental consequences.<br><br>
    In conclusion, while lithium-ion batteries have revolutionized modern technology and enabled numerous advancements, their widespread usage and improper disposal can have significant environmental implications.
        Emphasizing responsible manufacturing, recycling, and exploring greener alternatives are essential steps towards minimizing the impact of lithium-ion batteries on the environment.<br>
    </pBody>
  </div>
  </span>
  <br>

 <span>
  <button class="collapsible">GitHub Repo</button>
  <div class="content">
    <pBody>
      For more information about the project including design files, sources, and more, please visit our GitHub repository!
      <b>https://github.com/bogonissATWIT/RVBP</b><br>
      Our aim is to make the RVBP project <u>open source</u>, empowering others to leverage our work
      and maximize its positive impact on sustainability and battery recycling initiatives.<br>
    </pBody>
  </div>
  </span>
  <span>
  <button class="collapsible">Future Plans</button>
  <div class="content">
    <pBody>
      In the future, we envision expanding the RVBP (Recycled Vape Battery Pack) project with ambitious plans for hardware development and integration of additional peripherals.
      Our roadmap includes incorporating more sensors such as temperature/humidity sensors and flame sensors to enhance the monitoring capabilities and safety features of the battery pack.
       We also aim to integrate RVBP with popular smart home platforms like HomeAssistant and ESPHome, enabling seamless compatibility with a wide range of smart devices and automation systems. 
      Moreover, to make RVBP even more user-friendly and versatile, we plan to integrate with popular virtual assistants such as Alexa, Siri, and Google Home, allowing users to control and monitor the battery pack through voice commands.
       By embracing open-source principles, we are committed to fostering collaboration and innovation, ensuring that the RVBP project has a far-reaching and meaningful impact on sustainable energy solutions and eco-conscious practices.<br>
    </pBody>
  </div>
  </span>
  <button class="collapsible">User Manual</button>
    <div class="content">
      <pBody>
        To download the <b>user manual</b>, please visit the following url:<br>
        https://github.com/bogonissATWIT/RVBP/blob/main/Vape%20Recycling%20Battery%20Pack%20MANUAL%20(1).docx
      </pBody>
   </div>
  </span>
  <button class="collapsible">Credits</button>
  <div class="content">
    <pBody>
      Sam Bogonis, Matt Taylor, Aaron Lundgren<br>
      Advisor: Professor Saurav Basnet<br>
      Wentworth Institute of Technology 2023
    </pBody>
  </div>
  </span>
</body>
<!-- JavaScript Functions for Real-Time UI Data -->
<script>
  setInterval(function ( ) {
    var xhttp = new XMLHttpRequest();
    xhttp.onreadystatechange = function() {
      if (this.readyState == 4 && this.status == 200) {
        document.getElementById("temperature").innerHTML = this.responseText;
      }
    };
    xhttp.open("GET", "/temperature", true);
    xhttp.send();
  }, 10000 ) ;
  setInterval(function ( ) {
    var xhttp = new XMLHttpRequest();
    xhttp.onreadystatechange = function() {
      if (this.readyState == 4 && this.status == 200) {
        document.getElementById("humidity").innerHTML = this.responseText;
      }
    };
    xhttp.open("GET", "/humidity", true);
    xhttp.send();
  }, 10000 ) ;
  setInterval(function ( ) {
    var xhttp = new XMLHttpRequest();
    xhttp.onreadystatechange = function() {
      if (this.readyState == 4 && this.status == 200) {
        document.getElementById("v1voltage").innerHTML = this.responseText;
      }
    };
    xhttp.open("GET", "/v1voltage", true);
    xhttp.send();
  }, 10000 ) ;
  setInterval(function ( ) {
    var xhttp = new XMLHttpRequest();
    xhttp.onreadystatechange = function() {
      if (this.readyState == 4 && this.status == 200) {
        document.getElementById("v2voltage").innerHTML = this.responseText;
      }
    };
    xhttp.open("GET", "/v2voltage", true);
    xhttp.send();
  }, 10000 ) ;
  setInterval(function ( ) {
    var xhttp = new XMLHttpRequest();
    xhttp.onreadystatechange = function() {
      if (this.readyState == 4 && this.status == 200) {
        document.getElementById("v3voltage").innerHTML = this.responseText;
      }
    };
    xhttp.open("GET", "/v3voltage", true);
    xhttp.send();
  }, 10000 ) ;
  setInterval(function ( ) {
    var xhttp = new XMLHttpRequest();
    xhttp.onreadystatechange = function() {
      if (this.readyState == 4 && this.status == 200) {
        document.getElementById("totalvoltage").innerHTML = this.responseText;
      }
    };
    xhttp.open("GET", "/totalvoltage", true);
    xhttp.send();
  }, 10000 ) ;
  setInterval(function ( ) {
    var xhttp = new XMLHttpRequest();
    xhttp.onreadystatechange = function() {
      if (this.readyState == 4 && this.status == 200) {
        document.getElementById("chargepercent").innerHTML = this.responseText;
      }
    };
    xhttp.open("GET", "/chargepercent", true);
    xhttp.send();
  }, 10000 ) ;
  var coll = document.getElementsByClassName("collapsible");
  var i;
  for (i = 0; i < coll.length; i++) {
    coll[i].addEventListener("click", function() {
      this.classList.toggle("active");
      var content = this.nextElementSibling;
      if (content.style.maxHeight){
        content.style.maxHeight = null;
      } else {
        content.style.maxHeight = content.scrollHeight + "px";
      } 
    });
  }
</script>
</html>)rawliteral";

// SSID & Password
const char* ssid = "RVBP-Connect";  // Enter your SSID here
const char* password = "123456789";  //Enter your Password here

// IP Address details
IPAddress local_ip(192, 168, 4, 1);
IPAddress gateway(192, 168, 1, 1);
IPAddress subnet(255, 255, 255, 0);

AsyncWebServer server(80);  // Object of WebServer(HTTP port, 80 is defult)

//Display and DHT22 Setup
DHT DHT(THSense, DHT22); //Initalizes humid/temp sensor on pin 4 with make DHT22 
Adafruit_SSD1306 display(SCREEN_WIDTH, SCREEN_HEIGHT, &Wire, -1);

String readDHTTemperature(){
  float t = DHT.readTemperature(true);
  if (isnan(t)) {
    return "--";
  }
  else{
    Serial.println(t);
    return String(t);
  }
}

String readDHTHumidity(){
  float h = DHT.readHumidity();
  if (isnan(h)) {
    return "--";
  }
  else{
    Serial.println(h);
    return String(h);
  }
}

String processor(const String& var) {
  const int V1 = 36;
  const int V2 = 39;
  const int V3 = 34;

  float Pack1 = (analogRead(V1) / 4095.0) * 21.00;
  float Pack2 = (analogRead(V2) / 4095.0) * 21.00;
  float Pack3 = (analogRead(V3) / 4095.0) * 21.00;

  Serial.println(var);
  
  if(var == "TEMPERATURE"){
    return readDHTTemperature();
  }
  else if(var == "HUMIDITY"){
    return readDHTHumidity();
  }
  else if(var == "V1VOLTAGE"){
    return (String)Pack1;
  }
  else if(var == "V2VOLTAGE"){
    return (String)Pack2;
  }
  else if(var == "V3VOLTAGE"){
    return (String)Pack3;
  }
  else if(var == "CHARGEPERCENT"){
    return (String)((((Pack1 + Pack2 + Pack3) / (21.00 * 3))) * 100.00);
  }
  else if(var == "TOTALVOLTAGE"){
    return (String)(Pack1 + Pack2 + Pack3);
  }
  return String();
}

void displayWITSplash() {
    display.clearDisplay();
      display.drawBitmap(0,0, wit_logo, 128, 64, WHITE);
    display.display();
}

void displayNameSplash() {
    display.clearDisplay();
      display.setTextColor(WHITE);
      display.setTextSize(1);
      display.setFont(&Org_01);
      display.setCursor(0, 10);
      display.setTextWrap(0);
      display.setCursor(32, 10);
      display.println("Recycled Vape");
      display.setTextWrap(0);
      display.setCursor(18, 17);
      display.println("Battery Pack V2.10");
      display.drawLine(17, 20, 110, 20, 1);
      display.setCursor(30, 35);
      display.setTextWrap(0);
      display.setCursor(36, 35);
      display.println("Sam Bogonis");
      display.setTextWrap(0);
      display.setCursor(36, 42);
      display.println("Matt Taylor");
      display.setTextWrap(0);
      display.setCursor(28, 49);
      display.println("Aaron Lundgren");
      display.drawRect(24, 28, 80, 25, 1);
   display.display();
}

void displayTH() {
    display.clearDisplay();
      display.setCursor(5, 10);
      display.setFont(&Org_01);
      display.setTextSize(2);
      display.print("IP:");
      display.setCursor(40, 10);
      display.print("192.168.4.1");
      display.setCursor(10, 32);
      display.print("T:");
      display.setCursor(50, 32);
      display.print(readDHTTemperature() + "F");
      display.setCursor(10, 55);
      display.print("H:");
      display.setCursor(50, 55);
      display.print(readDHTHumidity() + "%");
      display.drawLine(0, 16, 128, 16, 1);
      display.drawLine(0, 40, 128, 40, 1);
    display.display();
}

void displayPackVoltage (String V1,String V2,String V3) { //(String)(analogRead(VX))
    display.clearDisplay();
      display.setCursor(5, 15);
      display.setTextSize(2);
      display.print("P1:");
      display.setCursor(50, 15);
      display.print(V1 + "V");
      display.setCursor(5, 37);
      display.print("P2:");
      display.setCursor(50, 37);
      display.print(V2 + "V");
      display.setCursor(5, 58);
      display.print("P3:");
      display.setCursor(50, 58);
      display.print(V3 + "V");
      display.drawLine(0, 22, 128, 22, 1);
      display.drawLine(0, 44, 128, 44, 1);
    display.display();
}

void setup() {
  //Pinmode setup
  pinMode(VPack_1, INPUT);
  pinMode(VPack_2, INPUT);
  pinMode(VPack_3, INPUT);
  pinMode(THSense, INPUT);
  pinMode(OUT_Toggle, OUTPUT);
  digitalWrite(OUT_Toggle, HIGH);

  DHT.begin();
  Wire.begin(21,22);

  Serial.begin(115200);

  // Create SoftAP
  WiFi.softAP(ssid, password);
  WiFi.softAPConfig(local_ip, gateway, subnet);

  Serial.print("Connect to My access point: ");
  Serial.println(ssid);

  server.on("/", HTTP_GET, [](AsyncWebServerRequest *request){
    request->send_P(200, "text/html", index_html, processor);
  });
  server.on("/temperature", HTTP_GET, [](AsyncWebServerRequest *request){
    request->send_P(200, "text/plain", readDHTTemperature().c_str());
  });
  server.on("/humidity", HTTP_GET, [](AsyncWebServerRequest *request){
    request->send_P(200, "text/plain", readDHTHumidity().c_str());
  });
 
  server.begin();
  Serial.println("HTTP server started");
  delay(100);

  //OLED Display setup
  if(!display.begin(SSD1306_SWITCHCAPVCC, 0x3C)) { // Address 0x3D for 128x64
      Serial.println(F("SSD1306 allocation failed"));
      for(;;);
    }

  //Splash Screens
  delay(2000);
  displayNameSplash();
  delay(2000);
  displayWITSplash();
  delay(2000);

}

void loop() {
  delay(2000);
  displayTH();
  delay(2000);
  displayPackVoltage((String)((analogRead(VPack_1)/4095) * 21.0) , (String)((analogRead(VPack_1)/4095) * 21.0), (String)((analogRead(VPack_1)/4095) * 21.0));
}

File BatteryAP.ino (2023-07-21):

/*
  WiFiAccessPoint.ino creates a WiFi access point and provides a web server on it.
  Created for arduino-esp32 on 04 July, 2018
  by Elochukwu Ifediora (fedy0)
*/

//Libraries necessary for below code
#include <WiFi.h>
#include <WiFiClient.h>
#include <DHT.h>
#include <WiFiAP.h>
#include <Wire.h>
#include <Adafruit_GFX.h>
#include <Adafruit_SSD1306.h>
#define SCREEN_WIDTH 128 // OLED display width, in pixels
#define SCREEN_HEIGHT 64 // OLED display height, in pixels

//Variable declarations
float voltage;
const char *ssid = "Battery";
const char *password = "password1234";
String header;
WiFiServer server(80);
Adafruit_SSD1306 display(SCREEN_WIDTH, SCREEN_HEIGHT, &Wire, -1); //Initializes the display with -1 as the reset pin
//Some functions that need to be initialized first to be called right away
//DHT dht(4, DHT22); //Initalizes humid/temp sensor on pin 4 with make DHT22 
/*
void readv() {
  float voltage = (float)analogRead(36) / 4096 * 21 * 3728.814 / 3000;
}
*/
/* Function to read from the humidity sensor
void dht() {
  float hum = dht.readHumidity();
  float tempc = dht.readTemperature();
  float tempf = dht.readTemperature(true);
}
*/
void setup() {
  Serial.begin(115200);
  Serial.println();
  //dht.begin();
  //Initialization of the Access Point for client connection
  Serial.println("Configuring access point...");
  if (!WiFi.softAP(ssid, password)) {
    log_e("Soft AP creation failed.");
    while(1);
  }
  IPAddress myIP = WiFi.softAPIP();
  Serial.print("AP IP address: ");
  Serial.println(myIP);
  server.begin();
  Serial.println("Server started");
  /* Initialization of the OLED display, commented out until PCB comes in and can be tested
  if(!display.begin(SSD1306_SWITCHCAPVCC, 0x3C)) { // Address 0x3D for 128x64
    Serial.println(F("SSD1306 allocation failed"));
    for(;;);
  }
  delay(2000);
  display.clearDisplay();
  display.setTextSize(1);
  display.setTextColor(WHITE);
  display.print(voltage,1);
  display.println("v.<br>");
  display.println("IP address: ");
  display.print(myIP);
  */
}
      
void loop() {
  String hum = String(random(0,100));
  String tempf = String(random(10,130));
  String tempc = String(random(-20, 45));
  WiFiClient client = server.available();   // listen for incoming clients
  if (client) {                             // if you get a client,
    Serial.println("New Client.");          // print a message out the serial port
    String currentLine = "";
    while (client.connected()) {            // loop while the client's connected
      if (client.available()) {
        char c = client.read();
        Serial.write(c);        //If client has information, read it and output to the serial monitor
        header += c;
        if (c == '\n') {
          if(currentLine.length() == 0) {
            client.println("HTTP/1.1 200 OK");
            client.println("Content-type:text/html");
            client.println();
            //Formatting for HTML web page
            client.println("<!DOCTYPE html><html>");
            client.println("<head><meta name=\"viewport\" content=\"width=device-width, initial-scale=1\">");
            client.println("<style>html { font-family: Helvetica; display: inline-block; text-align: center;}");
            client.println("h1 {background-color: #2a914e; border: groove; black: white; padding: 16px 30px;}");
            client.println("p {background-color: #000000; border: solid; padding: 16px 30px; color: white}");
            client.println("bad { color: #FF0000;}");
            client.println("good { color: #00FF00;}</style></head>");
            client.println("<h1>Battery Information</h1>");
            client.print("<p>Total Voltage/Voltage per Series Pack = 20.7V<br>");
            client.println("Battery Humidity = " + hum + "%<br>Safe?<good> Yes</good><br>");
            client.println("Battery Temperature = " + tempf + " F, " + tempc + " C<br>Safe?<bad> No</bad><br>");
            client.println("Battery Percentage = 98.5%</p>");
            client.println("</html>");
            client.println();
            break;
          }
          else {    // if you got a newline, then clear currentLine:
            currentLine = "";
          }
        }
        else if (c != '\r') {  // if you got anything else but a carriage return character,
          currentLine += c;    // add it to the end of the currentLine
        }
      }
    }
    header = "";
    // close the connection:
    client.stop();
    Serial.println("Client Disconnected.");
  }
}

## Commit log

2023-07-21 Schematic / Gerber / System Block Diagram Upload
    Version 4.0 and Version 5.0 gerber files, schematics, and associated system block diagrams.
    [BOM_PCB_ESP32_3_2023-06-22.csv, BOM_PCB_ESP32_4_2023-07-08 (1).csv, BOM_PCB_ESP32_4_2023-07-08 (1).xlsx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]
2023-07-21 First iteration code / Solidworks Parts
    Upload includes the first working .ino file for programming the ESP32-DEVKITC-32D Microcontroller, as well as the Solidworks files for the initial enclosure design and the presentation base.
    [Enclosure.SLDPRT, Enclosure.STL, presentation base.SLDPRT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]
2023-07-21 Bill of Materials (BOM)
    Bill of Materials for non-PCB/PCBA specific parts. The total cost of PCB manufacturing is included. Other BOMs for V4 and V5 can be found in their respective folders.
    [Bill of Materials (BOM).xlsx]
2023-08-04 RVBP-V4 Code Upload
    First major code update since initial creation of repo.
    Changes:
    - Full scale redesign on the RVBP Dashboard including support for Light/Dark mode
    - Added collapsible text areas for relevant information (About, Quick Facts, GitHub repo, Future Plans, User Manual, and Credits)
    -HTML/CSS/JS are now easily readable and editable (previously sent via a ton of client.println() commands)
    - Temperature and Humidity values now update in real time on the RVBP Dashboard
    - Pack voltage values, charge capacity, and total voltage should also now update in real time on RVBP Dashboard
    - Migrated to ESPAsyncWebServer library (May require manual install)
    - Custom IP Addresses can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
    [RVBP-V4.ino]
